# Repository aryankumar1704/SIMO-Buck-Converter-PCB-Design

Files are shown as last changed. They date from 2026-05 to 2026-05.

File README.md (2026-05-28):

# SIMO-Buck-Converter-PCB-Design
# Single-Input Multi-Output (SIMO) Buck Converter
Developed for the course **EE 396: Design Lab** at the Indian Institute of Technology (IIT), Guwahati under the supervision of Dr. Shabari Nath. This project demonstrates a synchronous **Single-Input Multi-Output (SIMO) Buck Converter** featuring complementary switching hardware, optical isolation, and digital control implemented on a Xilinx Artix-7 FPGA development board. The design replaces traditional freewheeling diodes with active synchronous switches to maximize power efficiency, time-sharing power from a common node out across three distinct output channels. Full schematics, Verilog hardware source modules, board footprints, and calculation scripts are detailed inside the project folder file bandgap_current_ref.pdf.
## Hardware Architecture & Design Parameters
The physical layout centers on a common switching hub driven by an primary power MOSFET and a synchronous rectifier switch ($U0/U\times1$) receiving complementary PWM gate signals. Downstream energy is distributed to three independent output rails via dedicated selection MOSFETs ($U1, U4, U3$) operating on a time-sharing network. Electrical isolation is maintained by feeding the digital FPGA control waveforms into high-speed HCPL3120 optocouplers powered through floating MGJ2D241509SC isolated DC-DC converters[cite: 2]. Operating from a $V_{in} = 20\text{ V}$ supply to target a $V_{out} = 10\text{ V}$ output at a $D = 0.5$ duty cycle, the power stage utilizes a calculated $560\ \mu\text{H}$ filter inductor and parallel $33\ \mu\text{F}$ electrolytic/SMD capacitor banks to split high and low-frequency noise. At a switching frequency of $f_s = 20\text{ kHz}$, theoretical calculations yield an inductor current ripple ($\Delta I_l$) of $\approx 0.45\text{ A}$ and a tight output voltage ripple ($\Delta V_{out}$) of $\approx 84.5\text{ mV}$.
## FPGA Pulse Control & Experimental Results
The control architecture is written in Verilog and targeted to a Digilent Nexys A7 100T FPGA board. Synchronous switching logic runs on an internal FSM counter that scales the native $100\text{ MHz}$ oscillator to $20\text{ kHz}$, enabling user-controlled toggling between $30\%$ and $50\%$ duty cycles using debounced mechanical input buttons. To guarantee safety and prevent destructive shoot-through current across the half-bridge, the Verilog code implements a strict hardware dead-time window of $200$ clock cycles, creating a $2\ \mu\text{s}$ delay where both control signals remain low. Bench testing validated the design via Tektronix and Keysight digital oscilloscopes. The recorded current and voltage waveforms confirm stable, continuous conduction mode (CCM) operation with ripple dynamics matching theoretical models, proving the viability of this FPGA-driven SIMO matrix for multi-rail power applications.



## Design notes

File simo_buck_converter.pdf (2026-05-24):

## SIMO Buck Converter

## EE 396: Design Lab

Shantanu Barai: 230108011

Aryan Kumar: 230108010

### Supervisor: Dr. Shabari Nath

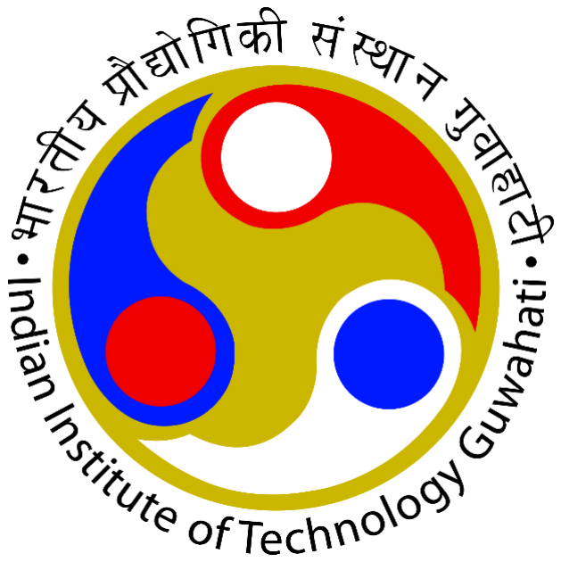
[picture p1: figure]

Department of Electronics and Electrical Engineering

Indian Institute of Technology, Guwahati

Guwahati, 781039

## Contents

- Introduction
- Circuits
- Power Circuit
- Driver Circuit
- Theoretical analysis
- Gate Pulse Generation using FPGA
- Board used
- Pulse Generation
- Logic
- Code
- PCB Design of our circuit
- Schematic
- Layout
- Results and Observations
- Bill of Materials
- Conclusion
- Future Work

## Introduction

Modern electronic systems often require multiple voltage levels from a single power source, making efficient power conversion essential. A DC–DC converter is used to convert one DC voltage level to another, and among these, the buck converter is widely used for stepping down voltage. In this project, a Single-Input Multi-Output (SIMO) buck converter is designed to generate three regulated output voltages from a single input using controlled MOSFET switching and filtering. This approach reduces component count, size, and overall system complexity while ensuring efficient power distribution. Such converters find applications in microcontroller and FPGA power supplies with multiple voltage rails, portable and battery-operated devices, IoT and communication systems, as well as automotive and other embedded electronic systems.

## Circuits

### - Power circuit

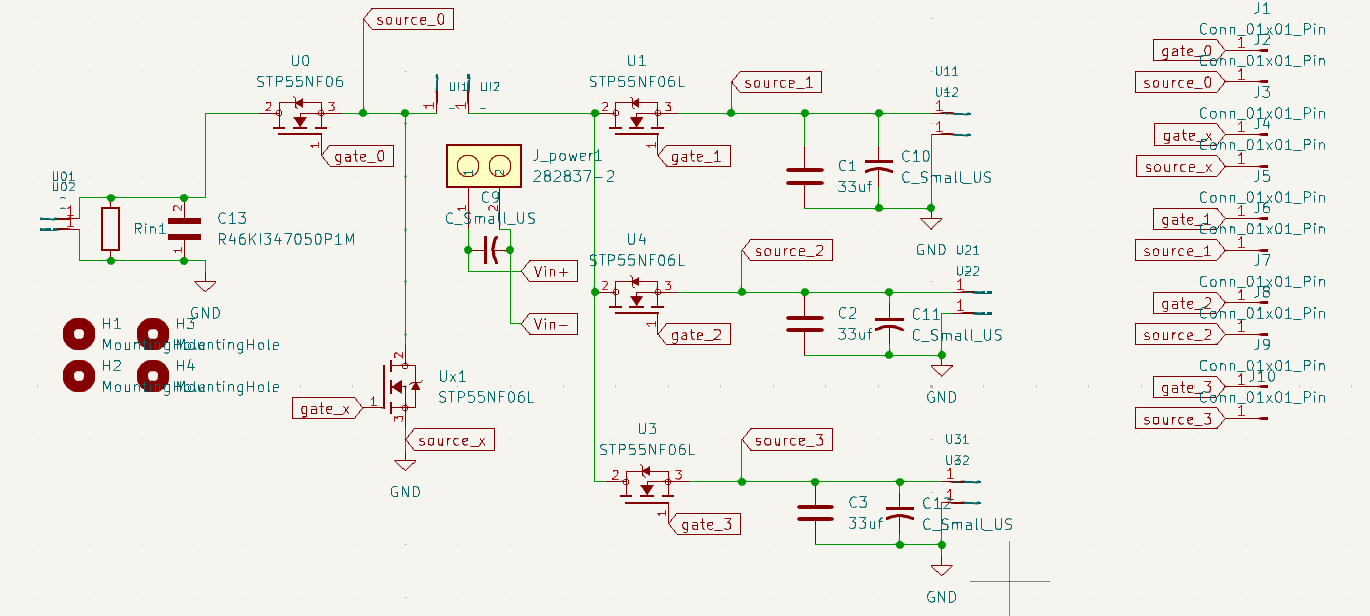
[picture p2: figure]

This circuit implements a Single-Input Multi-Output (SIMO) buck converter using multiple MOSFET switches. A single DC input is supplied at the left, which is first conditioned and then fed to a common switching node. The main switching MOSFET (U0/Ux1) controls the energy transfer from the input.

Those 2 Switches have complementary switching by supplying complementary PWMs into there gates using an FPGA.

From this common node, three separate MOSFETs (U1, U4, U3) are used to time-share the input energy across three output channels. Each MOSFET is driven by an independent gate signal (gate_1, gate_2, gate_3), allowing selective delivery of power to each output.

At each output, capacitors (C1, C2, C3 along with smaller parallel capacitors) act as filters, smoothing the pulsed voltage into stable DC outputs (source_1, source_2, source_3). The smaller SMD capacitors are used for filtering high frequency noises whereas electrolytic capacitors filter out low frequency noises. The connectors on the right provide access to gate signals and output nodes for control and measurement.

Overall, the circuit uses controlled switching and energy sharing to efficiently generate multiple regulated DC outputs from a single input source while minimizing component count.

## - Driver circuits

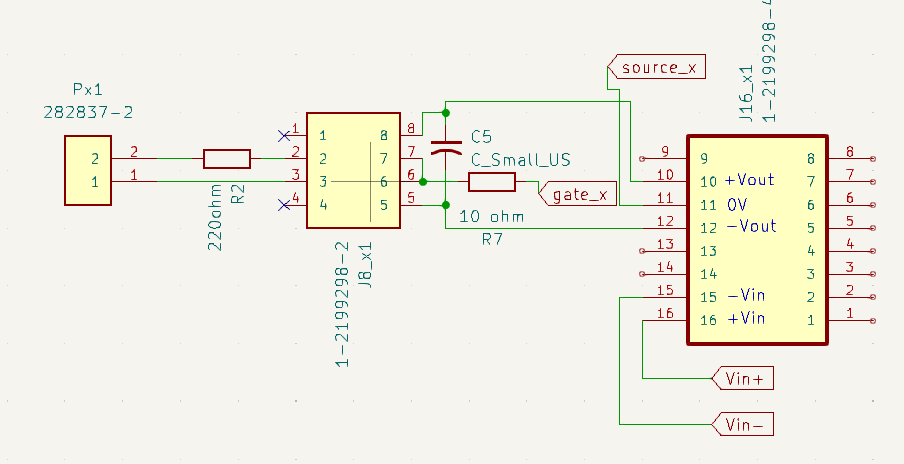
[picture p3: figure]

This circuit is an isolated gate-driving module where the input signal passes through an optocoupler (via a current-limiting resistor) to provide electrical isolation, and the optocoupler’s output, powered by a dedicated isolated DC-DC converter drives a MOSFET gate through a small resistor (to control switching speed) and a capacitor (to suppress noise and false triggering); by replicating this block, you independently control multiple MOSFETs in your system—one as the main switch, one replacing the diode for synchronous rectification, and the remaining for selecting which output is energized while maintaining isolation, noise immunity, and flexible floating operation.

## - Theoretical Analysis

Vin = 20 V
Vout = 10 V
Duty cycle (D) = 0.5
Inductor (L) = 560 µH = 560 × 10⁻⁶ H Capacitor (C) = 33 µF = 33 × 10⁻⁶ F Switching frequency (fₛ) = 20 kHz = 20000 Hz
1) Inductor Current Ripple (ΔIₗ):

ΔIₗ = [(Vin − Vout) × D] / (L × fₛ)

ΔIₗ = [(20 − 10) × 0.5] / (560 × 10⁻⁶ × 20000) ΔIₗ = 5 / 11.2
ΔIₗ ≈ 0.446 A
2) Output Voltage Ripple (ΔVout):

ΔVout = ΔIₗ / (8 × fₛ × C)

ΔVout = 0.446 / (8 × 20000 × 33 × 10⁻⁶) ΔVout = 0.446 / 5.28
ΔVout ≈ 0.0845 V

Final Results:
Inductor current ripple ≈ 0.45 A Output voltage ripple ≈ 84.5 mV

## Gate Pulse Generation using FPGA

## - FPGA (Nexys A7 100T)

The Nexys A7-100T is an FPGA development board based on the Xilinx Artix-7 (XC7A100T) featuring around 100k logic cells, 240 DSP slices, and ~4.8 Mb of block RAM, making it suitable for complex digital and control applications. It includes a built-in 100 MHz clock oscillator that can be scaled using internal PLL/MMCM blocks to generate required frequencies (like PWM signals), along with 128 MB DDR2 memory and 16 MB flash for storage. The board provides rich I/O such as switches, LEDs, seven-segment displays, UART, VGA, Ethernet, and Pmod connectors, and is commonly used with Vivado for FPGA-based system design.

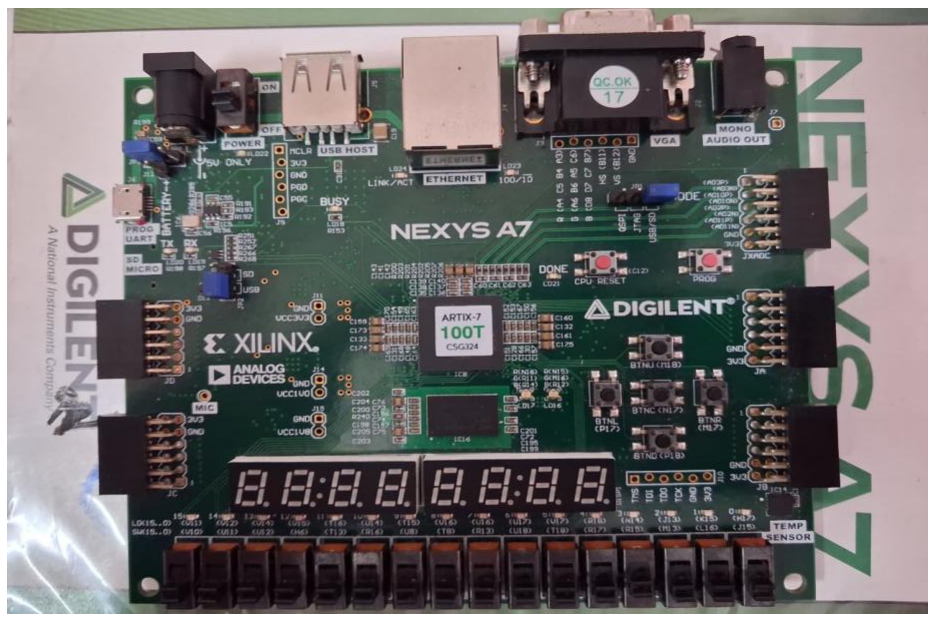
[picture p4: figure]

## - Pulse Generation

## Logic

This design implements Buck converter using an FPGA. Instead of a diode, a second MOSFET is used, making the system more efficient. The FPGA generates PWM signals, ensures safe switching using dead-time, and allows user control through buttons.

A counter running on a 100 MHz clock generates a periodic signal. Based on this, a PWM waveform is created with two selectable duty cycles: 30% and 50%. The duty cycle determines how long the high-side switch remains ON, thereby controlling the output voltage of the buck converter.

Complementary Switching:

Two outputs (pwm_a and pwm_b) drive two MOSFETs:

pwm_a → high-side switch

pwm_b → low-side switch

They operate in a complementary manner, ensuring that when one is ON, the other is OFF.

Dead Time Insertion between these two Complementary switches:

Dead-time is a short delay inserted between turning OFF one MOSFET and turning ON the other to prevent shoot-through in the synchronous buck converter. In your design, this is implemented using a counter (dead_cnt) inside an FSM, where both pwm_a and pwm_b remain OFF until the counter reaches the set value DEAD_TIME = 200. The duration of this delay depends on the clock period. With a clock frequency of 100 MHz, the clock period is T =
1
100×10⁶ = 10 ns. Therefore, the total dead-time is 200 × 10 ns = 2000 ns =

2 μs. This ensures safe switching, though a larger dead-time can slightly reduce efficiency due to diode conduction.

Multioutput Buttons and Debounce Logic:

Three debounced buttons control three switches (sw1, sw2, sw3). Each button press toggles its corresponding output using edge detection, ensuring one clean toggle per press.

Mechanical buttons produce noisy signals due to bouncing. The debounce module ensures that a button press is only registered after it remains stable for about 10 ms, preventing false triggering.

## Code

module pwm_deadtime_nexysA7_fixedDuty #(

parameter CLK_FREQ=100_000_000,parameter PWM_FREQ=20_000,parameter DEAD_TIME=200)(

input wire clk,input wire rst,

input wire duty_sel,

input wire btn1,input wire btn2,input wire btn3,

output reg pwm_a,output reg pwm_b,

output reg sw1,output reg sw2,output reg sw3);

// ================= PERIOD =================

localparam PERIOD=CLK_FREQ/PWM_FREQ;

localparam DUTY_30=(PERIOD*30)/100;

localparam DUTY_50=(PERIOD*50)/100;

wire[12:0] duty_selected;

assign duty_selected=(duty_sel)?DUTY_50:DUTY_30;

// ================= COUNTER =================

reg[12:0] counter;

always@(posedge clk or posedge rst) begin

if(rst) counter<=0;

else if(counter==PERIOD-1) counter<=0;

else counter<=counter+1;

end

// ================= RAW PWM =================

wire pwm_raw=(counter<duty_selected);

// ================= DEAD-TIME FSM =================

reg[15:0] dead_cnt;

reg state;

always@(posedge clk or posedge rst) begin

if(rst) begin pwm_a<=0;pwm_b<=0;state<=0;dead_cnt<=0;end

else begin

case(state)

0: begin

if(!pwm_raw) begin pwm_a<=0;pwm_b<=0;

if(dead_cnt<DEAD_TIME) dead_cnt<=dead_cnt+1;

else begin dead_cnt<=0;state<=1;end end

else begin pwm_a<=1;pwm_b<=0;dead_cnt<=0;end

end

1: begin

if(pwm_raw) begin pwm_a<=0;pwm_b<=0;

if(dead_cnt<DEAD_TIME) dead_cnt<=dead_cnt+1;

else begin dead_cnt<=0;state<=0;end end

else begin pwm_a<=0;pwm_b<=1;dead_cnt<=0;end

end

endcase end end

// ================= DEBOUNCE MODULE INSTANCES =================

wire db1,db2,db3;

debounce d1(.clk(clk),.rst(rst),.btn_in(btn1),.btn_out(db1));

debounce d2(.clk(clk),.rst(rst),.btn_in(btn2),.btn_out(db2));

debounce d3(.clk(clk),.rst(rst),.btn_in(btn3),.btn_out(db3));

// ================= TOGGLE LOGIC =================

reg db1_d,db2_d,db3_d;

always@(posedge clk or posedge rst) begin

if(rst) begin sw1<=0;sw2<=0;sw3<=0;db1_d<=0;db2_d<=0;db3_d<=0;end

else begin

if(db1&~db1_d) sw1<=~sw1;

if(db2&~db2_d) sw2<=~sw2;

if(db3&~db3_d) sw3<=~sw3;

db1_d<=db1;db2_d<=db2;db3_d<=db3;

end end

endmodule

## PCB Design of our circuit

Schematic | Layout

Power Circuit

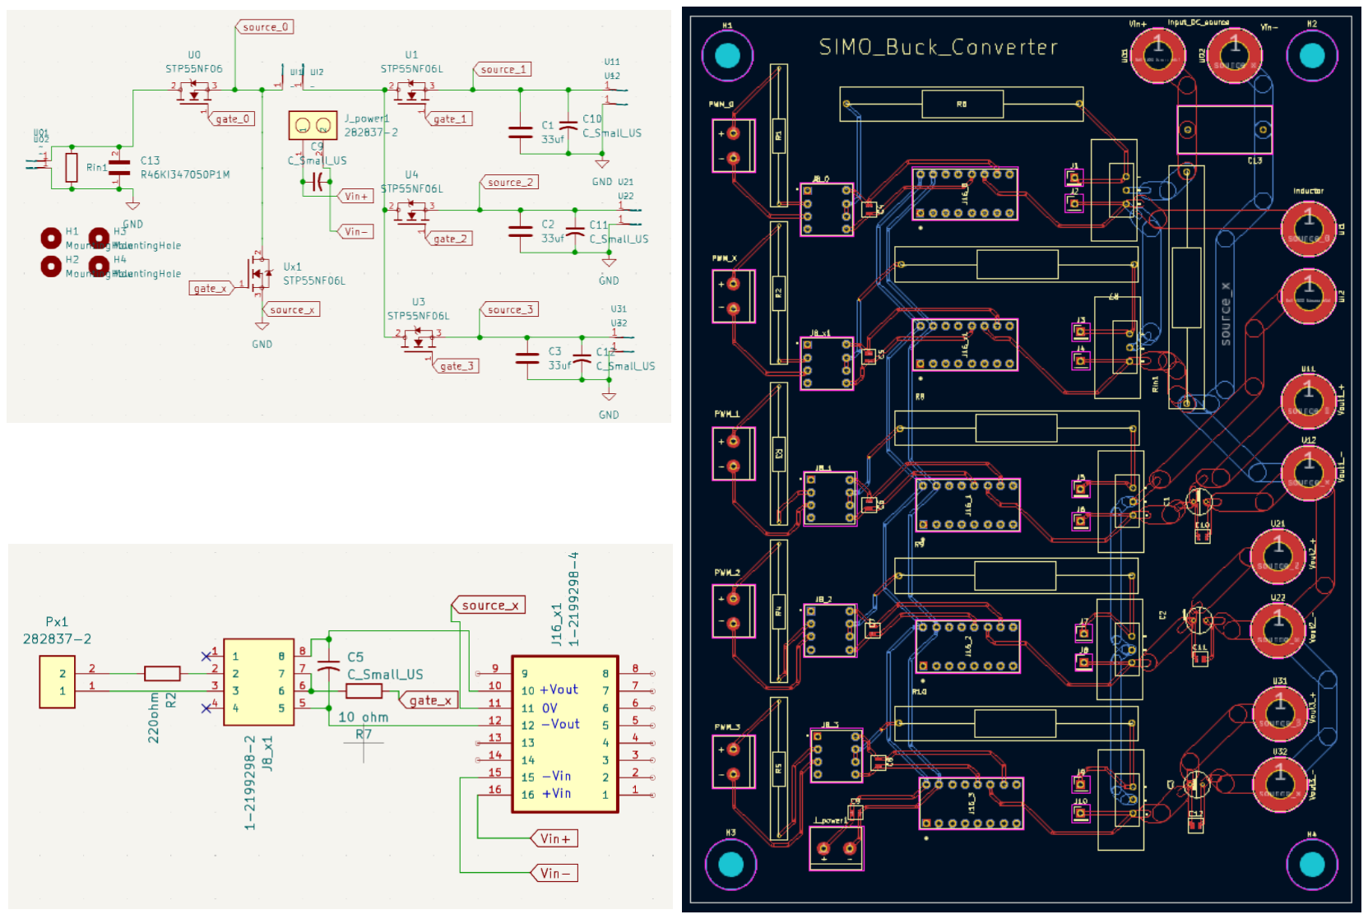
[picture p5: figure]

Driver Circuit | Dimensions of PCB: 13cm x 17.5cm

## Results and observations

### 1) PWM generated by FPGA:

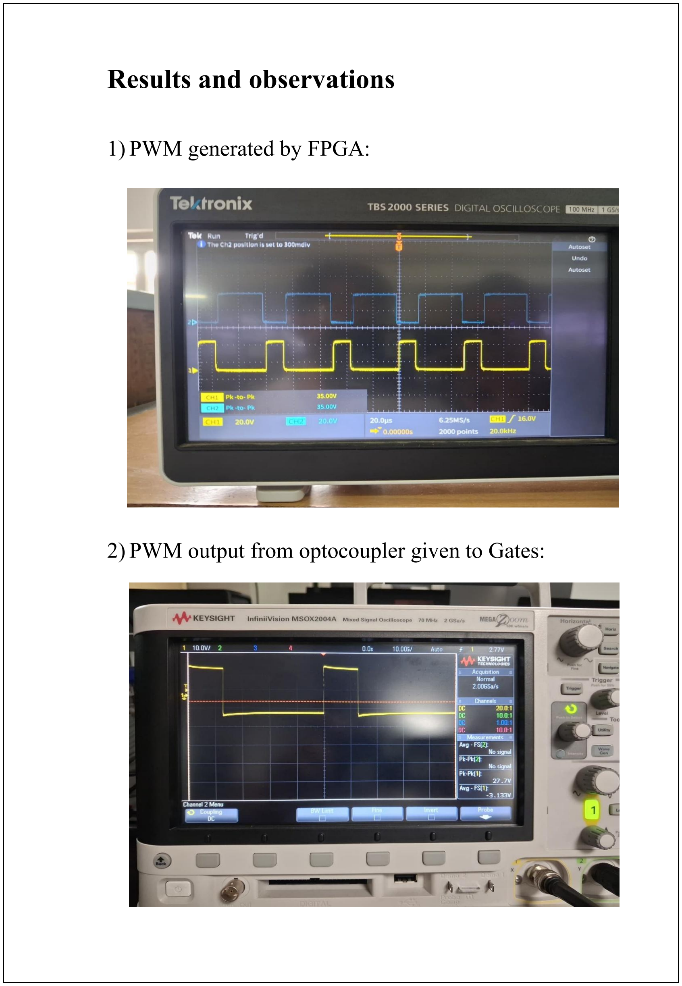
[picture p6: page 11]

### 2) PWM output from optocoupler given to Gates:

### 3) Inductor current and output voltage waveform:

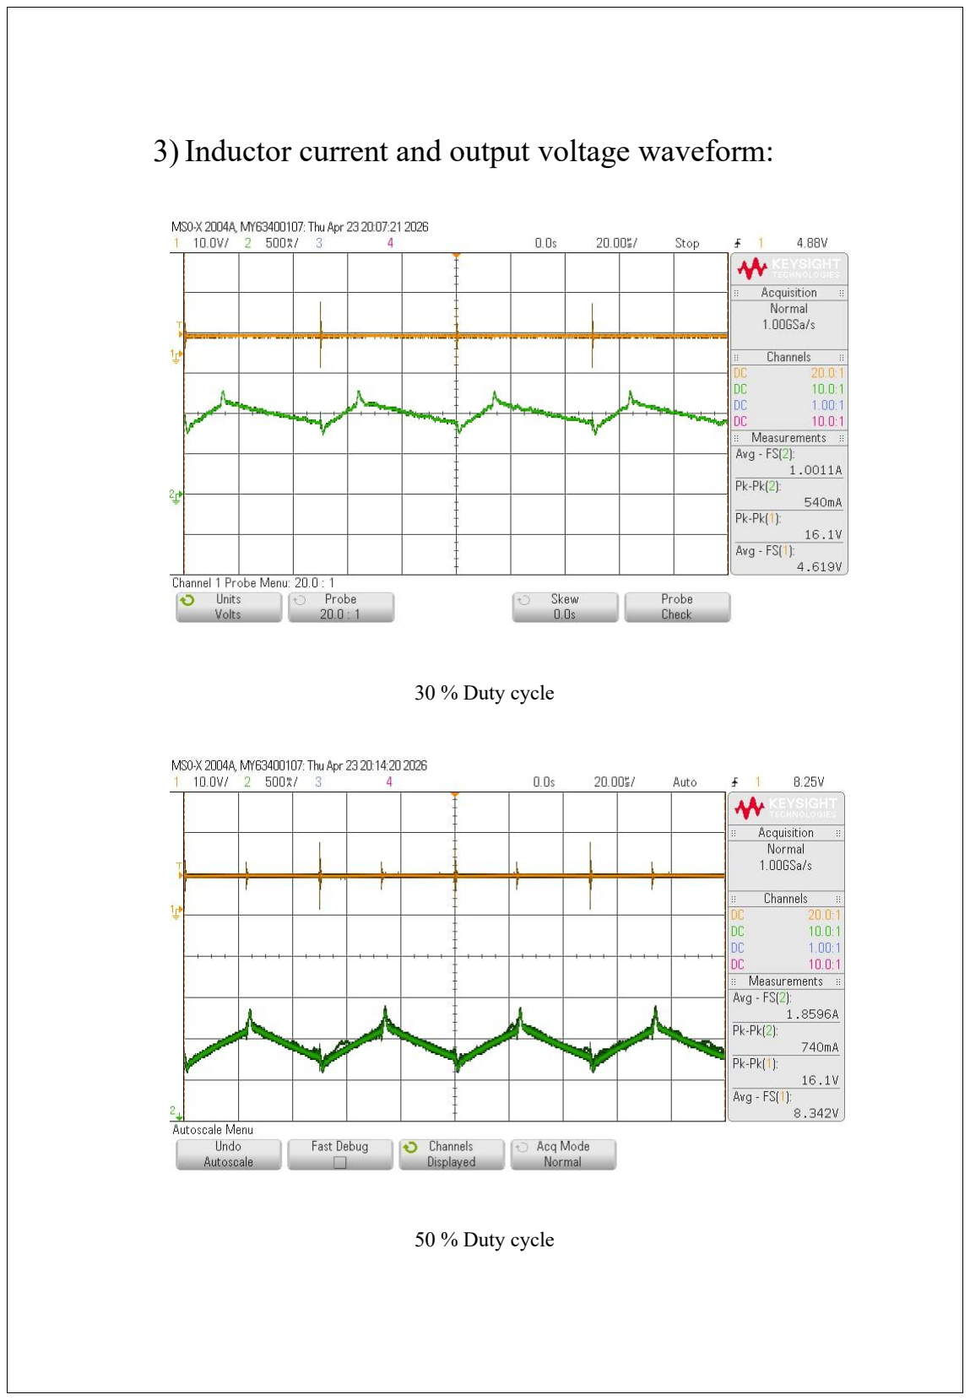
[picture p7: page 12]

30 % Duty cycle

50 % Duty cycle

## Bill of Materials

A Bill of Materials (BOM) is an essential component of any hardware design project, providing a detailed list of all components used in the circuit. It includes critical information such as the part name, manufacturer, part number, quantity, value.

Sr no. | Component | Part no. | Specification | Manufacturer | Quantity
1 | Terminal Blocks 5mm | MaiXu_MX126-5.0-02P | Pitch = 5mm | MAX Asian Brands | 6
2 | Optocouplers | HCPL3120 | 2.5A 3750Vrms 8-DIP | BROADCOM | 5
3 | Isolated DC-DC converter | MGJ2D241509S C | 15V -8.7V 80mA, 40mA 21.6V - 26.4V | MURATA POWER SOLUTIONS | 5
4 | N channel MOSFETS | STP55NF06 | 60 V 50A 110W | STMicroelectr onics | 5
5 | Metallized polypropylene Film capacitor | X2 MKP | 0.47uF 310VAC | STcapacitors | 1
6 | MLCC SMD Capacitor | 08051C104JAT2 A | 0.1 uF, 100 V, 0805 | KYOCERA AVX | 9
7 | Electrolytic capacitors | MCKSK050M33 0D11S | 33uF 50V | MULTICORP RPO | 3

## Results

The buck converter was successfully analyzed for the given parameters, yielding an inductor current ripple of approximately 0.45 A and an output voltage ripple of about 84.5 mV, confirming proper operation in continuous conduction mode and validating the chosen component values for stable performance.

## Conclusion

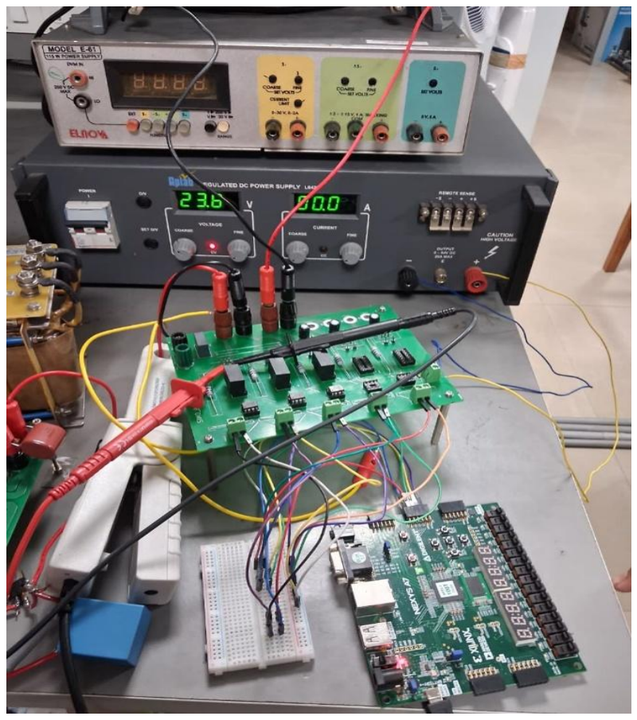
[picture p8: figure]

The designed buck converter with the given parameters operates effectively, producing the desired output voltage with controlled inductor current ripple and acceptable output voltage ripple. The use of appropriate inductance, capacitance, and switching frequency ensures stable operation in continuous conduction mode (CCM), while the overall system demonstrates reliable performance for regulated DC power conversion and validates the theoretical design calculations.

## Future Work (Closed-Loop Control)

Future improvements can focus on implementing a closed-loop control system to achieve precise output voltage regulation under varying load and input conditions. By incorporating feedback (via voltage sensing) and using a controller such as PID implemented on an FPGA (e.g., Nexys A7), the duty cycle can be dynamically adjusted to minimize steady-state error, reduce ripple further, and improve transient response. Additionally, advanced control techniques and optimized gate driving can enhance efficiency, stability, and overall performance of the converter.

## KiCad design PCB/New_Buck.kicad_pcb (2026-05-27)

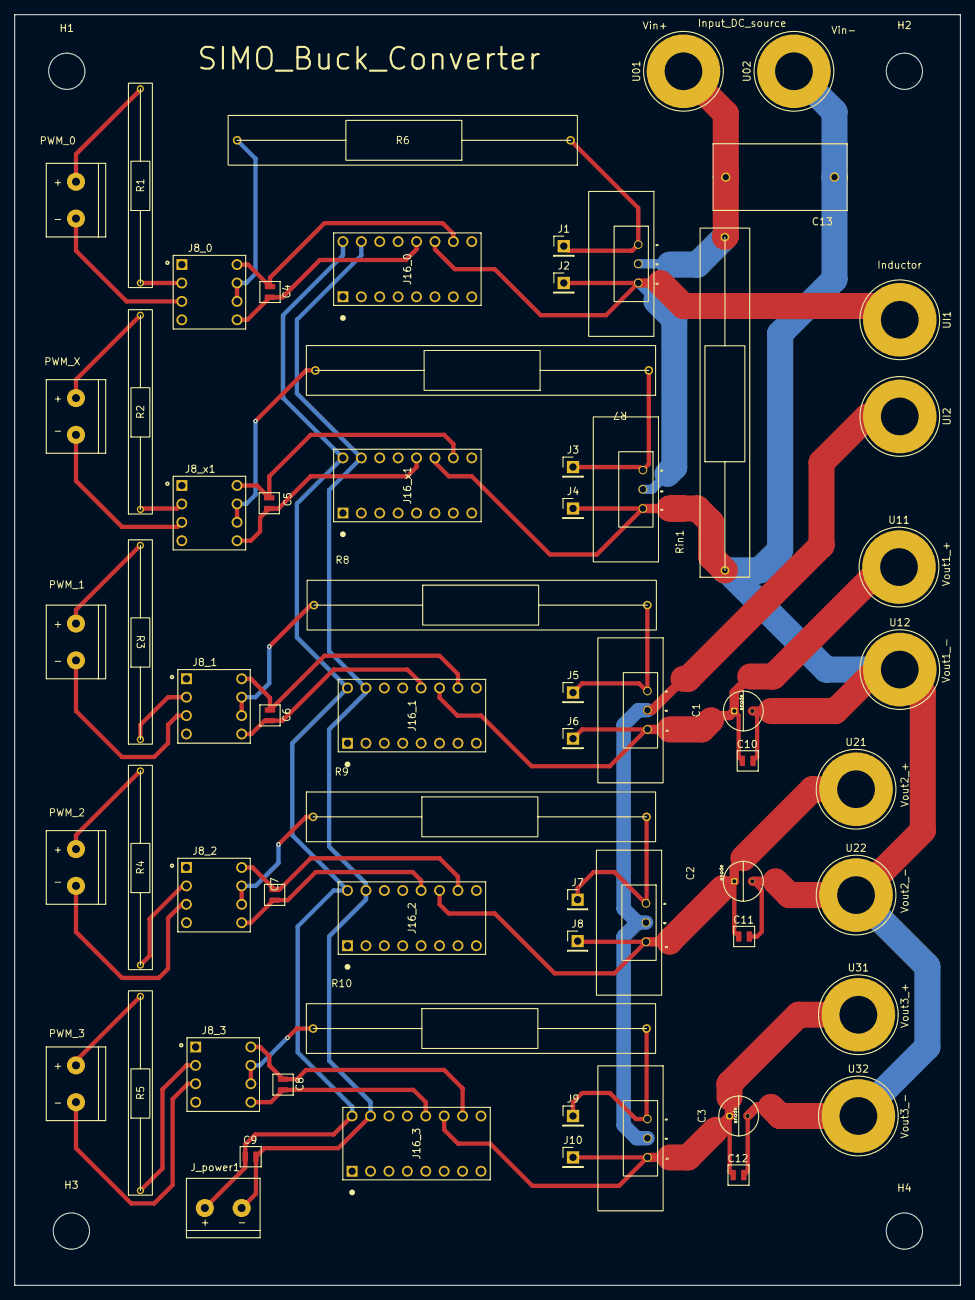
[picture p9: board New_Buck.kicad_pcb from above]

Board: 2 copper layers, 130.5 x 175.3 mm, 69 parts (0 on the bottom side), 44 nets.

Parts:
C1, C2, C3: 33uf; MCKSK050M330D11S
C4: 0.1 uf; C0805C104K5RACTU
C5, C6, C7, C8, C9, C10, C11, C12: C_Small_US; C0805C104K5RACTU
C13: R46KI347050P1M; CAPRR1500W60L1850T920H1260
H1, H2, H3, H4: MountingHole; MountingHole_5mm
J1, J2, J3, J4, J5, J6, J7, J8, J9, J10: Conn_01x01_Pin; PinHeader_1x01_P2.54mm_Vertical
J8_0, J8_1, J8_2, J8_3, J8_x1: 1-2199298-2; TE_1-2199298-2
J16_0, J16_1, J16_2, J16_3, J16_x1: 1-2199298-4; TE_1-2199298-4
J_power1: 282837-2; TE_282837-2
P0, P1, P2, P3: 282837-2; TE_282837-2
Px1: 282837-2; TE_282837-2
R1, R2, R3: 220ohm; CFR-25JT-52-220R
R4, R5: 220 ohm; CFR-25JT-52-220R
R6, R7, R8, R9, R10: 10 ohm; ROX3SJ10R
Rin1: 10 ohm; ROX3SJ10R
U0: STP55NF06; STP55NF06_nchannel_mosfet
U01, U02, U11, U12, U21, U22, U31, U32: Banana_Jack_1Pin_4mm
U1, U3, U4: STP55NF06L; STP55NF06_nchannel_mosfet
UI1, UI2: Banana_Jack_1Pin_4mm
Ux1: STP55NF06L; STP55NF06_nchannel_mosfet

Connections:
unnamed: C4.1, J8_0.8, J16_0.10
unnamed: C4.2, J8_0.5, J16_0.12
unnamed: C5.1, J8_x1.8, J16_x1.10
unnamed: C5.2, J8_x1.5, J16_x1.12
unnamed: C6.1, J8_1.8, J16_1.10
unnamed: C6.2, J8_1.5, J16_1.12
unnamed: C7.1, J8_2.8, J16_2.10
unnamed: C7.2, J8_2.5, J16_2.12
unnamed: C8.1, J8_3.8, J16_3.10
unnamed: C8.2, J8_3.5, J16_3.12
unnamed: J8_0.2, R1.1
unnamed: J8_0.3, P0.1
unnamed: J8_0.6, J8_0.7, R6.2
unnamed: J8_1.2, R3.1
unnamed: J8_1.3, P1.1
unnamed: J8_1.6, J8_1.7, R8.1
unnamed: J8_2.2, R4.1
unnamed: J8_2.3, P2.1
unnamed: J8_2.6, J8_2.7, R9.1
unnamed: J8_3.2, R5.1
unnamed: J8_3.3, P3.1
unnamed: J8_3.6, J8_3.7, R10.1
unnamed: J8_x1.2, R2.1
unnamed: J8_x1.3, Px1.1
unnamed: J8_x1.6, J8_x1.7, R7.2
unnamed: P0.2, R1.2
unnamed: P1.2, R3.2
unnamed: P2.2, R4.2
unnamed: P3.2, R5.2
unnamed: Px1.2, R2.2
unnamed: C13.2, Rin1.2, U0.2, U01.1 (banana_pin)
unnamed: U1.2, U3.2, U4.2, UI2.1 (banana_pin)
Vin+: C9.1, J16_0.16, J16_1.16, J16_2.16, J16_3.16, J16_x1.16, J_power1.1
Vin-: C9.2, J16_0.15, J16_1.15, J16_2.15, J16_3.15, J16_x1.15, J_power1.2
gate_0: J1.1, R6.1, U0.1
gate_1: J5.1, R8.2, U1.1
gate_2: J7.1, R9.2, U4.1
gate_3: J9.1, R10.2, U3.1
gate_x: J3.1, R7.1, Ux1.1
source_0: J2.1, J16_0.11, U0.3, UI1.1 (banana_pin), Ux1.2
source_1: C1.1, C10.1, J6.1, J16_1.11, U1.3, U11.1 (banana_pin)
source_2: C2.1, C11.1, J8.1, J16_2.11, U4.3, U21.1 (banana_pin)
source_3: C3.1, C12.1, J10.1, J16_3.11, U3.3, U31.1 (banana_pin)
source_x: C1.2, C2.2, C3.2, C10.2, C11.2, C12.2, C13.1, J4.1, J16_x1.11, Rin1.1, U02.1 (banana_pin), U12.1 (banana_pin), U22.1 (banana_pin), U32.1 (banana_pin), Ux1.3

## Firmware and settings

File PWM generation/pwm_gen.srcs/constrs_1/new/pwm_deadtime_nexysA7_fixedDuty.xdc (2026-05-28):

set_property IOSTANDARD LVCMOS33 [get_ports btn1]
set_property IOSTANDARD LVCMOS33 [get_ports btn2]
set_property IOSTANDARD LVCMOS33 [get_ports btn3]
set_property IOSTANDARD LVCMOS33 [get_ports clk]
set_property IOSTANDARD LVCMOS33 [get_ports duty_sel]
set_property IOSTANDARD LVCMOS33 [get_ports pwm_a]
set_property IOSTANDARD LVCMOS33 [get_ports pwm_b]
set_property IOSTANDARD LVCMOS33 [get_ports rst]
set_property IOSTANDARD LVCMOS33 [get_ports sw1]
set_property IOSTANDARD LVCMOS33 [get_ports sw2]
set_property IOSTANDARD LVCMOS33 [get_ports sw3]
set_property PACKAGE_PIN E3 [get_ports clk]
set_property PACKAGE_PIN P17 [get_ports btn1]
set_property PACKAGE_PIN N17 [get_ports btn2]
set_property PACKAGE_PIN M17 [get_ports btn3]
set_property PACKAGE_PIN J15 [get_ports duty_sel]
set_property PACKAGE_PIN C17 [get_ports pwm_a]
set_property PACKAGE_PIN D18 [get_ports pwm_b]
set_property PACKAGE_PIN L16 [get_ports rst]
set_property PACKAGE_PIN E18 [get_ports sw1]
set_property PACKAGE_PIN G17 [get_ports sw2]
set_property PACKAGE_PIN D17 [get_ports sw3]

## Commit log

2026-05-24 Add image to README for SIMO Buck Converter project
2026-05-27 Create PCB
